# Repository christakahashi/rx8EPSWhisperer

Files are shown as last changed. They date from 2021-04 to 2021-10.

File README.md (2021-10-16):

# WARNING
Operating a modified production car can be dangerous or life threatening.  Don't do it.  This project is only for testing your powersteering components in either an otherwise inoperable car or under SLOW SAFE conditions and NEVER on the road or in public. 

# rx8EPSWhisperer
This is a hack to recover the power steering on an RX8 power steering rack thats not longer connected to the ECU.

It reads a potentiometer connected to ADC7 to determine the power steering assist level.

# Hardware
The hardware was designed to be multipurpose as either a CAN sensor interface or to enable the EPS on an RX8.  All components were choosen to be AEC-Q100/AEC-Q200 qualified or have variants that are qualified.  It shoudn't matter for bench test use, but if that matters to you then make sure to buy the right variants.

# Hookup
Connect 12v, ground, CAN+, CAN-, to their respective connections.  If you don't have external termination please close the termination jumper on the PCB.  
To wire it you can either cut the wires on your connector short and run them directly into the PCB making it directly hang off the EPS computer, or you can run longer wires from the 4 pin connector.  Either way 12v and ground need to be connected to the cars accessory power.  

# NOTES
- This isn't a product if anything here doesn't make sense or makes you nervous don't use this hardware/software.
- The can library came modified from atmel, now microchip.  The license referred to in the source for that library can no longer be found, but if its like similar libraries from atmel its free to use as long as its only used on atmel chips.  The licene text file included with this repository only applies to the non-library files.  If you represent atmel/microchip and have clarification or want me to remove the library please contact me.

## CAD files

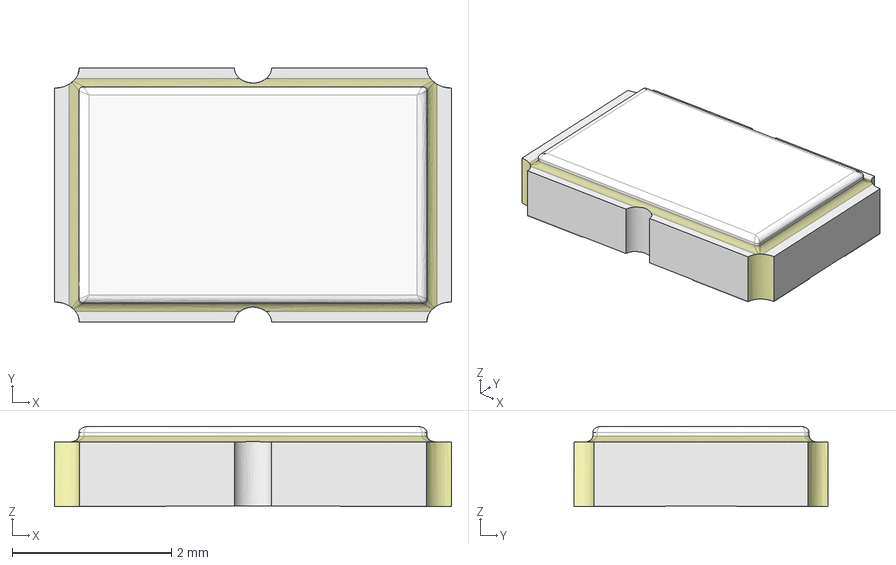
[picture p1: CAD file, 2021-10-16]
PCB/footprints/xtal_osc_5x3.2.step
4.99 x 3.20 x 1.01 mm

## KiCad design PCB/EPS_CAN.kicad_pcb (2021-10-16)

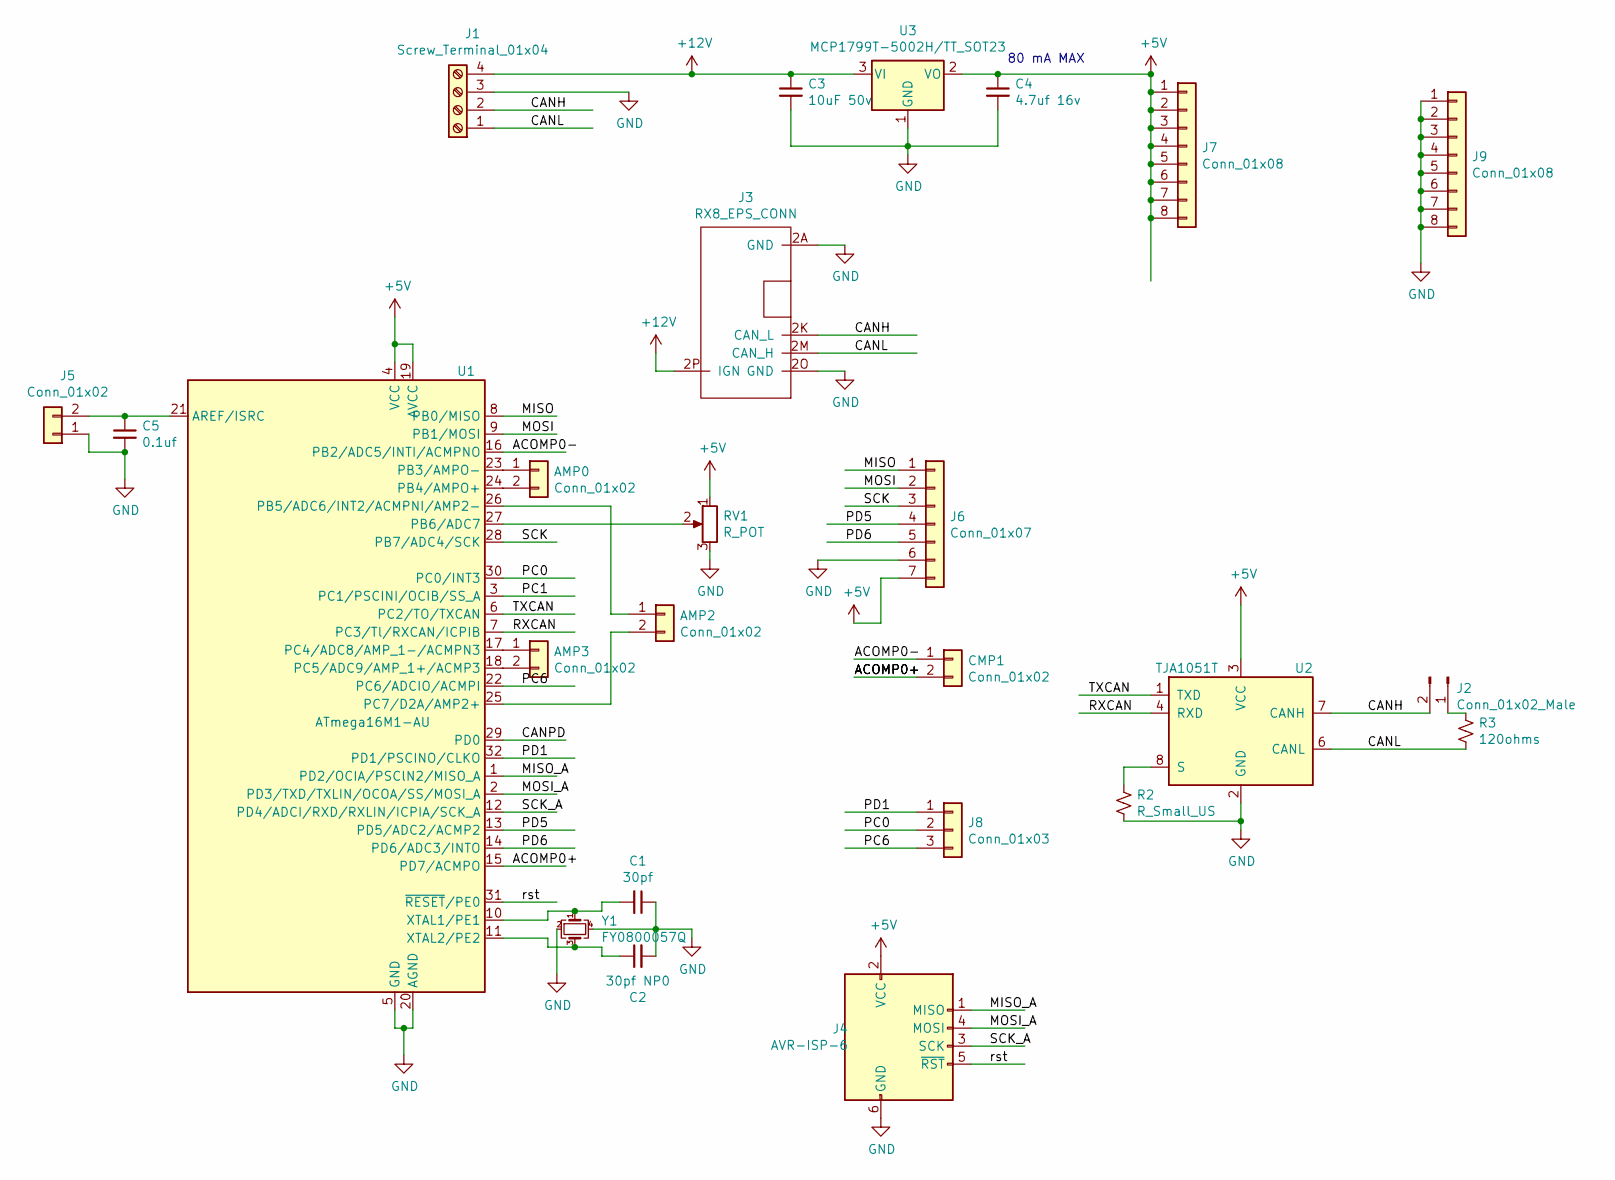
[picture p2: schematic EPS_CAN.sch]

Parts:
AMP0, AMP2, AMP3: Conn_01x02; PinHeader_1x02_P2.54mm_SPECIALSILK
C1: 30pf; C_0603_1608Metric
C2: 30pf NP0; C_0603_1608Metric
C3: 10uF 50v; C_1210_3225Metric
C4: 4.7uf 16v; C_0805_2012Metric
C5: 0.1uf; C_0805_2012Metric
CMP1: Conn_01x02; PinHeader_1x02_P2.54mm_SPECIALSILK
J1: Screw_Terminal_01x04; PhoenixContact_MSTBVA_2,5_4-G-5,08_1x04_P5.08mm_Vertical
J2: Conn_01x02_Male; PinHeader_1x02_P2.54mm_Vertical
J3: RX8_EPS_CONN; RX8_EPS_F
J4: AVR-ISP-6; PinHeader_2x03_P2.54mm_Vertical_SMD
J5: Conn_01x02; PinHeader_1x02_P2.54mm_Vertical
J6: Conn_01x07; PinHeader_1x07_P2.54mm_Vertical
J7, J9: Conn_01x08; PinHeader_1x08_P2.54mm_Vertical
J8: Conn_01x03; PinHeader_1x03_P2.54mm_Vertical
R2: R_Small_US; R_0805_2012Metric
R3: 120ohms; R_0805_2012Metric
RV1: R_POT; Potentiometer_Bourns_3314J_Vertical
U1: ATmega16M1-AU; TQFP-32_7x7mm_P0.8mm
U2: TJA1051T; SOIC-8_3.9x4.9mm_P1.27mm
U3: MCP1799T-5002H/TT_SOT23; SOT-23
Y1: FY0800057Q; Crystal_SMD_5032-4Pin_5.0x3.2mm

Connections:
+5V: C4.1, J4.2 (VCC), J6.7, J7.1, J7.2, J7.3, J7.4, J7.5, J7.6, J7.7, J7.8, RV1.1, U1.4 (VCC), U1.19 (AVCC), U2.3 (VCC), U3.2 (VO)
+12V: C3.1, J1.4, J3.2P (IGN), U3.3 (VI)
/ACOMP0+: CMP1.2, U1.15 (PD7/ACMPO)
/ACOMP0-: CMP1.1, U1.16 (PB2/ADC5/INTI/ACMPNO)
/CANH: J1.2, J2.2, J3.2K (CAN_L), U2.7 (CANH)
/CANL: J1.1, J3.2M (CAN_H), R3.2, U2.6 (CANL)
/CANPD: U1.29 (PD0)
/MISO: J6.1, U1.8 (PB0/MISO)
/MISO_A: J4.1 (MISO), U1.1 (PD2/OCIA/PSClN2/MISO_A)
/MOSI: J6.2, U1.9 (PB1/MOSI)
/MOSI_A: J4.4 (MOSI), U1.2 (PD3/TXD/TXLIN/OCOA/SS/MOSI_A)
/PC0: J8.2, U1.30 (PC0/INT3)
/PC1: U1.3 (PC1/PSCINI/OCIB/SS_A)
/PC6: J8.3, U1.22 (PC6/ADCIO/ACMPI)
/PD1: J8.1, U1.32 (PD1/PSCINO/CLKO)
/PD5: J6.4, U1.13 (PD5/ADC2/ACMP2)
/PD6: J6.5, U1.14 (PD6/ADC3/INTO)
/RXCAN: U1.7 (PC3/Tl/RXCAN/ICPIB), U2.4 (RXD)
/SCK: J6.3, U1.28 (PB7/ADC4/SCK)
/SCK_A: J4.3 (SCK), U1.12 (PD4/ADCI/RXD/RXLIN/ICPIA/SCK_A)
/TXCAN: U1.6 (PC2/TO/TXCAN), U2.1 (TXD)
/rst: J4.5 (~RST), U1.31 (~RESET~/PE0)
GND: C1.1, C2.2, C3.2, C4.2, C5.2, J1.3, J3.2A (GND), J3.2O (GND), J4.6 (GND), J5.1, J6.6, J9.1, J9.2, J9.3, J9.4, J9.5, J9.6, J9.7, J9.8, R2.1, RV1.3, U1.5 (GND), U1.20 (AGND), U2.2 (GND), U3.1 (GND), Y1.2, Y1.4
unnamed: AMP0.1, U1.23 (PB3/AMPO-)
unnamed: AMP0.2, U1.24 (PB4/AMPO+)
unnamed: AMP2.1, U1.26 (PB5/ADC6/INT2/ACMPNI/AMP2-)
unnamed: AMP2.2, U1.25 (PC7/D2A/AMP2+)
unnamed: AMP3.1, U1.17 (PC4/ADC8/AMP_1-/ACMPN3)
unnamed: AMP3.2, U1.18 (PC5/ADC9/AMP_1+/ACMP3)
unnamed: C1.2, U1.10 (XTAL1/PE1), Y1.1
unnamed: C2.1, U1.11 (XTAL2/PE2), Y1.3
unnamed: C5.1, J5.2, U1.21 (AREF/ISRC)
unnamed: J2.1, R3.1
unnamed: R2.2, U2.8 (S)
unnamed: RV1.2, U1.27 (PB6/ADC7)

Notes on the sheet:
80 mA MAX

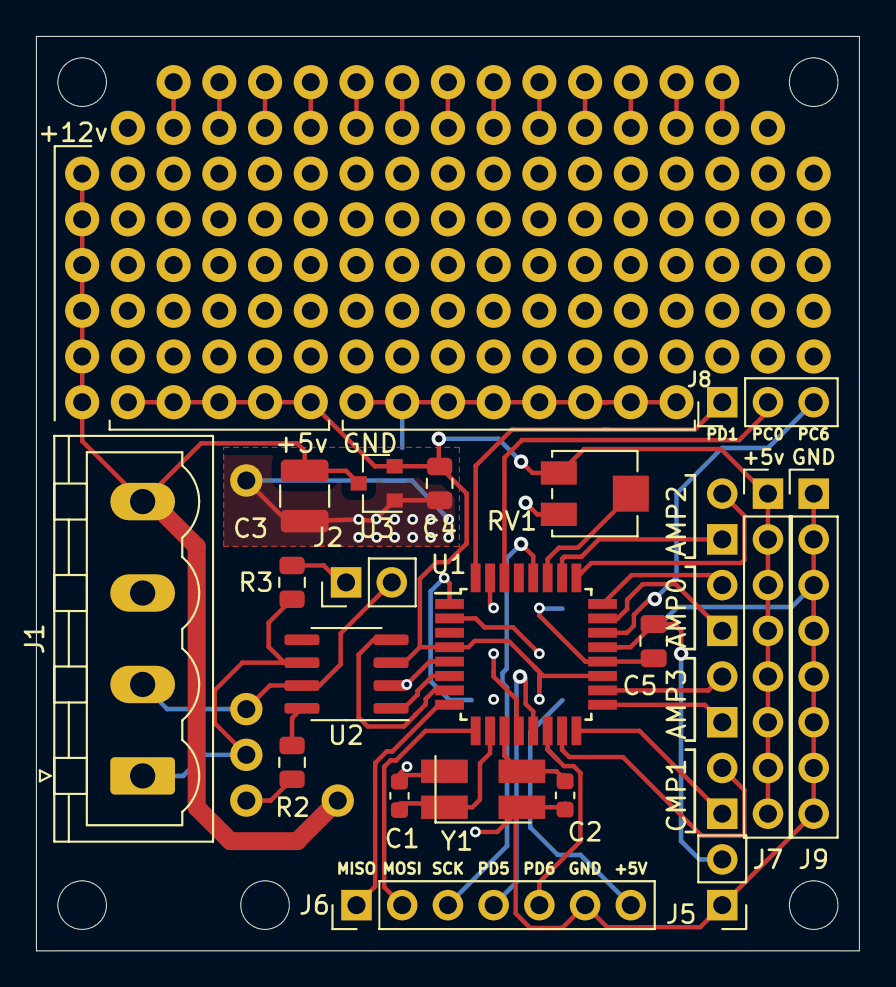
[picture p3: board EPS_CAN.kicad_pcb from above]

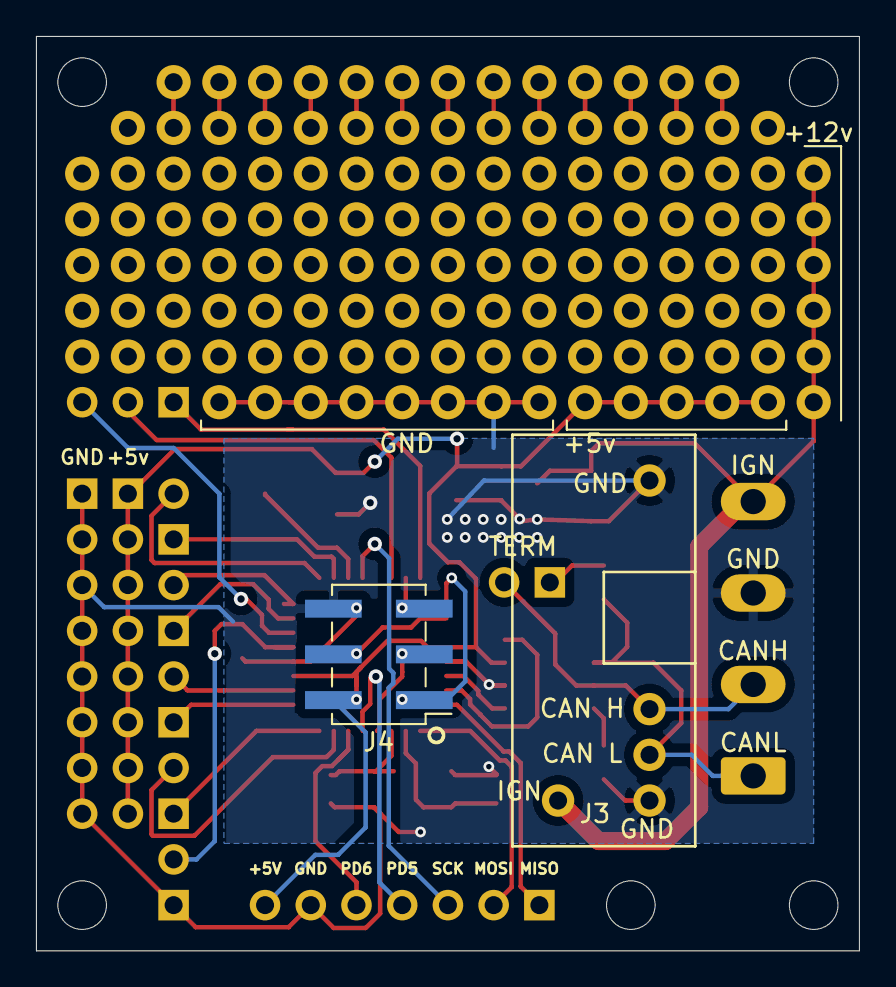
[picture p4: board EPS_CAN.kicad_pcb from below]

Board: 2 copper layers, 45.7 x 50.8 mm, 25 parts (2 on the bottom side), 33 nets.

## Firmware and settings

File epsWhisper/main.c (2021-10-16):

/*
 * epsWhisper.c
 *
 * Created: 12/7/2020 10:03:09 PM
 * Author : chris
 */ 

#include <avr/io.h>
#include <avr/cpufunc.h>
#include "config.h"  //for f_cpu needeb by delay
#include <util/delay.h>
#include "can_lib.h" 

//utility to convert kph to the 2byte can 
#define KPH2SIG(x) ( (uint16_t)((x*100)+10000) )

st_cmd_t msg201;
//load with default known working values.
uint8_t payload[8] = {0x0d,0xd4,0xff,0xff,0x27,0x10,0x14,0xff};
    

void suart_tx(uint8_t);
void init_suart();
void init_ADC(void);
uint8_t read_ADC(void);
void print_byte(uint8_t ad);

int main(void)
{ 
    uint8_t ad;
    uint8_t adcVal;
    //just in case make sure the clk is unscaled.
    CLKPR = 0x80;
    CLKPR = 0x00;
    
    init_suart();
    can_init(0);

    sei();  //enable interrupts now
    init_ADC();
    
     
    while (1) {
        adcVal = read_ADC();
        ad = adcVal>>2;
        payload[4] =0x27+ad;  //0-100mph.
        
        msg201.pt_data = payload;
        msg201.ctrl.ide = 0; //2.0A std frame.
        msg201.dlc = sizeof(payload); //number of bytes sent.
        msg201.id.std = 0x201;
        msg201.cmd = CMD_TX; 
        //spin on cmd until accepted, should never spin in my code though
        // as I'm not sending a lot of messages and the bus should be mostly free.
        
        while(can_cmd(&msg201) != CAN_CMD_ACCEPTED);
        
        
        
        //print_byte(ad);
        //suart_tx('\n');


        //send every 100ms TODO: make this exactly periodic
        // supposed to be 10ms, but 100ms is fine and will save some power(heat).
        _delay_ms(100); 
        
        //call needed no matter what.  it frees the message.
        while(can_get_status(&msg201) == CAN_STATUS_NOT_COMPLETED); // Wait for Tx to complete
        
    }
}

void print_byte(uint8_t ad){
    char c;
    //some testing stuff
    if ( (ad>>4 &0x0f) >9){
        c = (ad>>4 &0x0f)-10+'A';
        } else {
        c = (ad>>4 &0x0f)+'0';
    }
    suart_tx(c);
    if ( (ad & 0x0f) >9){
        c = (ad  &0x0f)-10+'A';
        } else {
        c = (ad  &0x0f)+'0';
    }
    suart_tx(c);
}

void init_ADC() {
    //Avcc no ext cap.  ADC port 7.  left align bytes.
    ADMUX =  (1<<REFS0)| (1<<ADLAR) | (1<<MUX2) | (1<<MUX1) | (1<<MUX0);
    DIDR0 = 1<<ADC6D; //turn off digital input on adc6 
    //enable adc, set clk 125khz
    ADCSRA = (1<<ADEN) | (1<<ADPS2) | (1<<ADPS1); 
    ADCSRB = 0; //just incase.
    ADCSRA |= 1<<ADSC;  //start a conversion just to set things up
    while(ADCSRA & (1<<ADSC));  //wait for conv to end.
    
}

uint8_t read_ADC() {
    ADCSRA |= 1<<ADSC;  //start a conversion just to set things up
    while(ADCSRA & (1<<ADSC));  //wait for conv to end.
    
    return ADCH;
}




#define SS_DDR_PORT DDRB
#define SS_PORT PORTB
#define SS_PIN 2


void init_suart(){
    SS_DDR_PORT |= 1<<SS_PIN;
}

void suart_tx(uint8_t c) { 
    //139 clocks at 8mhz is (close to) 57600 bps =17.3611us
    
    //START BIT
    SS_PORT &=~(1<<SS_PIN);
    __builtin_avr_delay_cycles(139-1);
    
    
    for(uint8_t x=8;x>0;x--) {//4 instructions i think
        //each branch 6 instructions
        if (c&1) {
            SS_PORT |=1<<SS_PIN;  //sbi = 1 cycle
        }
        else {
            SS_PORT &=~(1<<SS_PIN); //cbi = 1 cycle
            //its shaky which branch the nops go.  
            // it depends on if the compiler uses SBIC or SBIS
            // inline asm would be smarter... but im lazy.
            _NOP();
            _NOP(); 
            _NOP();
        }
        c = c>>1; // 1 inst
        //not going to lie,
        // I tweaked the delays with a scope until it was right.
        __builtin_avr_delay_cycles(139-6-4);
    }
    //stop bit
    SS_PORT |= 1<<SS_PIN;
    //don't bother with delay here since I'll call other code.
    
}

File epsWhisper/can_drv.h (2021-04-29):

/*
 * can_drv.h
	
	The contents of this file were originally from the CAN Software Library
	provided by Atmel written for AT90CAN devices. The contents were modified
	for use with ATmegaxxM1 devices. Use of this file is subject to Atmel's 
	End User License Agreement.
 
	NOTE from user: these files came from:
	https://www.digikey.com/eewiki/display/microcontroller/CAN+Example+-+ATmega32M1+-+STK600
	I cannot find the license.txt that was referenced below as it was not included.
 */ 

//******************************************************************************
//! @file $RCSfile: can_drv.h,v $
//!
//! Copyright (c) 2007 Atmel.
//!
//! Use of this program is subject to Atmel's End User License Agreement.
//! Please read file license.txt for copyright notice.
//!
//! @brief This file contains the prototypes and the macros of the
//!        low level functions (drivers) of:
//!             - CAN (Controller Array Network)
//!             - for AT90CAN128/64/32.
//!
//! This file can be parsed by Doxygen for automatic documentation generation.
//! This file has been validated with AVRStudio-413528/WinAVR-20070122.
//!
//! @version $Revision: 3.20 $ $Name: jtellier $
//!
//! @todo
//! @bug
//******************************************************************************

#ifndef _CAN_DRV_H_
#define _CAN_DRV_H_

#include "config.h"

//_____ I N C L U D E S ________________________________________________________

//_____ D E F I N I T I O N S __________________________________________________

    // ----------
#ifndef FOSC
#  error  You must define FOSC in "config.h" file
#endif
    // ----------
#ifndef CAN_BAUDRATE
#  error  You must define CAN_BAUDRATE in "config.h" file
#endif
#define CAN_AUTOBAUD    0
    // ----------
#if FOSC == 16000             //!< Fclkio = 16 MHz, Tclkio = 62.5 ns
#   if   CAN_BAUDRATE == 100       //!< -- 100Kb/s, 16x Tscl, sampling at 75%
#       define CONF_CANBT1  0x12       // Tscl  = 10x Tclkio = 625 ns
#       define CONF_CANBT2  0x0C       // Tsync = 1x Tscl, Tprs = 7x Tscl, Tsjw = 1x Tscl
#       define CONF_CANBT3  0x37       // Tpsh1 = 4x Tscl, Tpsh2 = 4x Tscl, 3 sample points
#   elif CAN_BAUDRATE == 125       //!< -- 125Kb/s, 16x Tscl, sampling at 75%
#       define CONF_CANBT1  0x0E       // Tscl  = 8x Tclkio = 500 ns
#       define CONF_CANBT2  0x0C       // Tsync = 1x Tscl, Tprs = 7x Tscl, Tsjw = 1x Tscl
#       define CONF_CANBT3  0x37       // Tpsh1 = 4x Tscl, Tpsh2 = 4x Tscl, 3 sample points
#   elif CAN_BAUDRATE == 200       //!< -- 200Kb/s, 16x Tscl, sampling at 75%
#       define CONF_CANBT1  0x08       // Tscl  = 5x Tclkio = 312.5 ns
#       define CONF_CANBT2  0x0C       // Tsync = 1x Tscl, Tprs = 7x Tscl, Tsjw = 1x Tscl
#       define CONF_CANBT3  0x37       // Tpsh1 = 4x Tscl, Tpsh2 = 4x Tscl, 3 sample points
#   elif CAN_BAUDRATE == 250       //!< -- 250Kb/s, 16x Tscl, sampling at 75%
#       define CONF_CANBT1  0x06       // Tscl  = 4x Tclkio = 250 ns
#       define CONF_CANBT2  0x0C       // Tsync = 1x Tscl, Tprs = 7x Tscl, Tsjw = 1x Tscl
#       define CONF_CANBT3  0x37       // Tpsh1 = 4x Tscl, Tpsh2 = 4x Tscl, 3 sample points
#   elif CAN_BAUDRATE == 500       //!< -- 500Kb/s, 8x Tscl, sampling at 75%
#       define CONF_CANBT1  0x06       // Tscl = 4x Tclkio = 250 ns
#       define CONF_CANBT2  0x04       // Tsync = 1x Tscl, Tprs = 3x Tscl, Tsjw = 1x Tscl
#       define CONF_CANBT3  0x13       // Tpsh1 = 2x Tscl, Tpsh2 = 2x Tscl, 3 sample points
#   elif CAN_BAUDRATE == 1000      //!< -- 1 Mb/s, 8x Tscl, sampling at 75%
#       define CONF_CANBT1  0x02       // Tscl  = 2x Tclkio = 125 ns
#       define CONF_CANBT2  0x04       // Tsync = 1x Tscl, Tprs = 3x Tscl, Tsjw = 1x Tscl
#       define CONF_CANBT3  0x13       // Tpsh1 = 2x Tscl, Tpsh2 = 2x Tscl, 3 sample points
#   elif CAN_BAUDRATE == CAN_AUTOBAUD  // Treated later in the file
#       define CONF_CANBT1  0x00       // Unused
#       define CONF_CANBT2  0x00       // Unused
#       define CONF_CANBT3  0x00       // Unused
#   else
#       error This CAN_BAUDRATE value is not in "CAN_driver.h" file
#   endif

#elif FOSC == 12000           //!< Fclkio = 12 MHz, Tclkio = 83.333 ns
#   if   CAN_BAUDRATE == 100       //!< -- 100Kb/s, 20x Tscl, sampling at 75%
#       define CONF_CANBT1  0x0A       // Tscl  = 6x Tclkio = 500 ns
#       define CONF_CANBT2  0x0E       // Tsync = 1x Tscl, Tprs = 8x Tscl, Tsjw = 1x Tscl
#       define CONF_CANBT3  0x4B       // Tpsh1 = 6x Tscl, Tpsh2 = 5x Tscl, 3 sample points
#   elif CAN_BAUDRATE == 125       //!< -- 125Kb/s, 16x Tscl, sampling at 75%
#       define CONF_CANBT1  0x0A       // Tscl  = 6x Tclkio = 500 ns
#       define CONF_CANBT2  0x0C       // Tsync = 1x Tscl, Tprs = 7x Tscl, Tsjw = 1x Tscl
#       define CONF_CANBT3  0x37       // Tpsh1 = 4x Tscl, Tpsh2 = 4x Tscl, 3 sample points
#   elif CAN_BAUDRATE == 200       //!< -- 200Kb/s, 20x Tscl, sampling at 75%
#       define CONF_CANBT1  0x04       // Tscl  = 3x Tclkio = 250 ns
#       define CONF_CANBT2  0x0E       // Tsync = 1x Tscl, Tprs = 8x Tscl, Tsjw = 1x Tscl
#       define CONF_CANBT3  0x4B       // Tpsh1 = 6x Tscl, Tpsh2 = 5x Tscl, 3 sample points
#   elif CAN_BAUDRATE == 250       //!< -- 250Kb/s, 16x Tscl, sampling at 75%
#       define CONF_CANBT1  0x04       // Tscl  = 3x Tclkio = 250 ns
#       define CONF_CANBT2  0x0C       // Tsync = 1x Tscl, Tprs = 7x Tscl, Tsjw = 1x Tscl
#       define CONF_CANBT3  0x37       // Tpsh1 = 4x Tscl, Tpsh2 = 4x Tscl, 3 sample points
#   elif CAN_BAUDRATE == 500       //!< -- 500Kb/s, 12x Tscl, sampling at 75%
#       define CONF_CANBT1  0x02       // Tscl  = 2x Tclkio = 166.666 ns
#       define CONF_CANBT2  0x08       // Tsync = 1x Tscl, Tprs = 5x Tscl, Tsjw = 1x Tscl
#       define CONF_CANBT3  0x25       // Tpsh1 = 3x Tscl, Tpsh2 = 3x Tscl, 3 sample points
#   elif CAN_BAUDRATE == 1000      //!< -- 1 Mb/s, 12x Tscl, sampling at 75%
#       define CONF_CANBT1  0x00       // Tscl  = 1x Tclkio = 83.333 ns
#       define CONF_CANBT2  0x08       // Tsync = 1x Tscl, Tprs = 5x Tscl, Tsjw = 1x Tscl
#       define CONF_CANBT3  0x25       // Tpsh1 = 3x Tscl, Tpsh2 = 3x Tscl, 3 sample points
#   elif CAN_BAUDRATE == CAN_AUTOBAUD  // Treated later in the file
#       define CONF_CANBT1  0x00       // Unused
#       define CONF_CANBT2  0x00       // Unused
#       define CONF_CANBT3  0x00       // Unused
#   else
#       error This CAN_BAUDRATE value is not in "can_drv.h" file
#   endif
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

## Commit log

2021-04-29 fixed the only sending 6 msg thing. and added POT to adjust 'speed' from 0-161kph aka 0-100mph
    [can_drv.h, main.c]
2021-10-16 new adc channel
2021-10-16 fixed mixed spaces and tabs...
    [main.c]
2021-10-16 added PCB
    [EPS_CAN.kicad_pcb, EPS_CAN.sch, xtal_osc_5x3.2.step]
